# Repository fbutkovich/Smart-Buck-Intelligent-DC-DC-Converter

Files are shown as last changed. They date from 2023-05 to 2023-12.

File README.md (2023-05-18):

# Smart Buck Intelligent DC-DC Converter
Buck topology voltage converter with power monitoring functionality using the TI INA219 current sense IC.

The provided package includes the source code, necessary dependencies, PCB design, and 3D model files for a buck topology printed circuit board. This PCB is designed to efficiently power various devices, including a dedicated astronomy camera, using a higher voltage lithium-ion battery as the input source. A notable feature of this project design is the inclusion of power monitoring functionality through the utilization of the Texas Instruments INA219 Zero-Drift current/power monitor integrated circuit. The converter's output is a regulated 12 volts DC, capable of delivering up to 3 amperes of current, achieved by employing the Texas Instruments LM2596 SIMPLE SWITCHER 3A Step-Down Voltage Regulator. This configuration proves particularly beneficial when powering a dedicated astrophotography camera with active CMOS sensor cooling. The ability to monitor the camera's power consumption in relation to the fixed temperature setpoint and the surrounding environmental temperature adds significant value to this setup.

The barrel jack style connectors used for the voltage input and output are standard 5.5x2.1mm size, which is very common amongst astronomy equipment and many other consumer electronics.

The embedded firmware for the converter runs on the Microchip SAMD21E17A ARM Cortex M0 microcontroller, and can relay power monitoring statistics to a connected computer over a serial communications port.

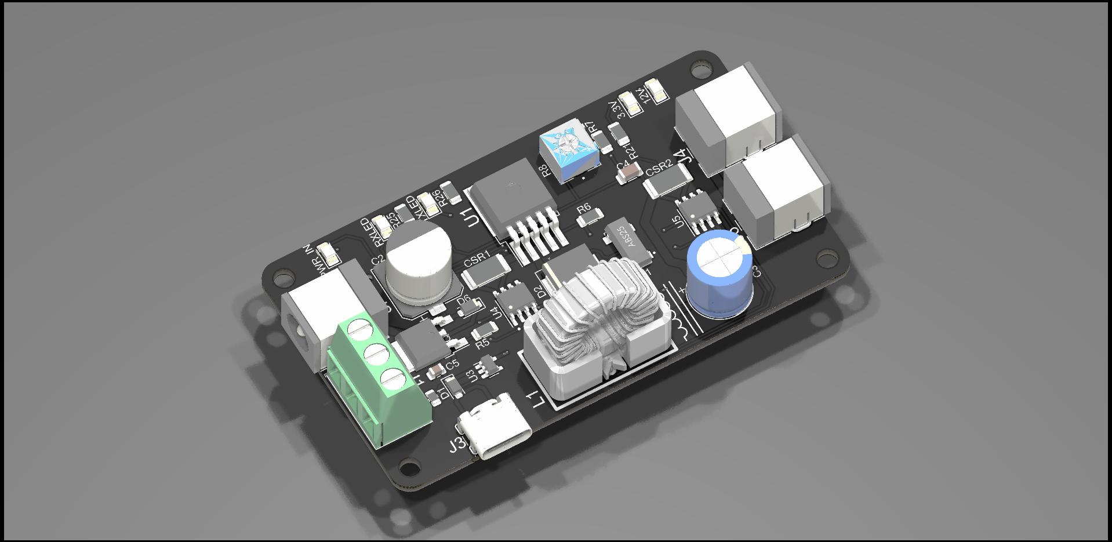
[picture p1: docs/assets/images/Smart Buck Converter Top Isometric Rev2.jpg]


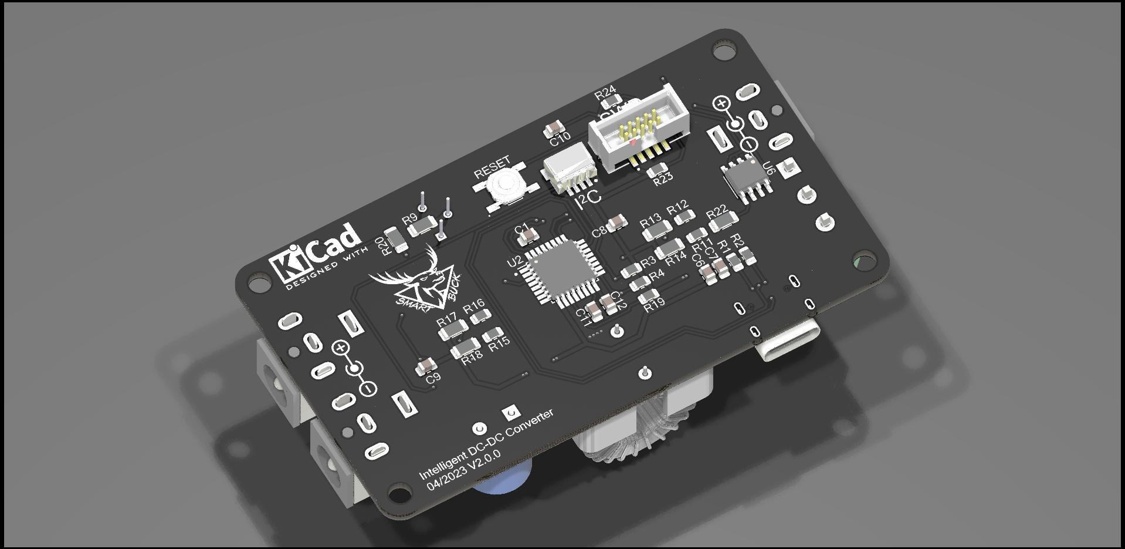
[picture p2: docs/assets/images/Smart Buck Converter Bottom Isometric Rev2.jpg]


The input screw terminal block is intended to be connected to a power tool battery using an “power wheels adapter”, which is fundamentally a flying lead breakout for the voltage of common power tool battery packs (Dewalt, Milwaukee, Makita etc.) that allows replacement of the standard lead-acid battery that comes in most childrens motorized cars.

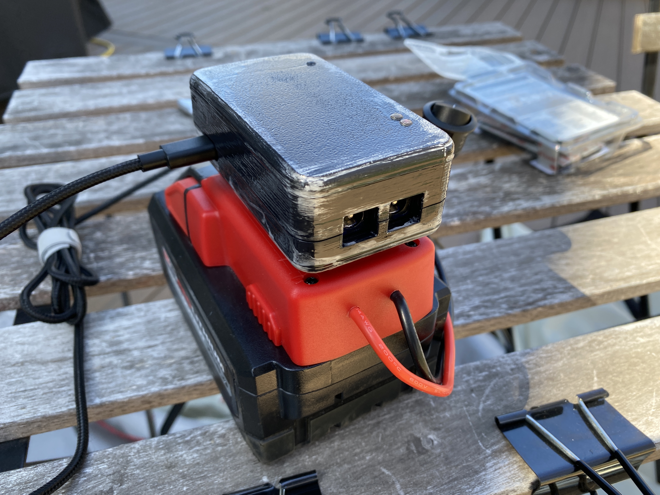
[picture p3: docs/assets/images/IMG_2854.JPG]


After the order and assembly of the first revision, as to be expected with any new electronic design there were several mistakes I ended up throubleshooting, thus leading to a few cuts and jumpers on the PCB itself. All of the corrections to the initial design were translated to the current revision of the schematic and layout and include:

* Ground plane disconnected from GND pins of U2, causing numerous headaches when attempting to flash bootloader onto IC and debug.
* Wrong pinout on U6, causing GND to be disconnected and frying IC upon first powerup. STCS05DR symbol and footprint were downloaded directly  from SnapEDA, however it was later discovered they were incorrect for KiCad.
* SWCLK signal needed 1kOhm pullup resistor for the SWD interface to work properly.
* Pinout of reset button was incorrect, again this components (TL3342F160QG) symbol and footprint for KiCad were sourced from SnapEDA, however the symbol led to the ground being connected to pushbutton in the normally     closed position, causing the microcontroller to be in a constant state of reset.
* Footprint size and capacity of feed-forward capacitor required for the LM2596 adjustable buck regulator were incorrect.

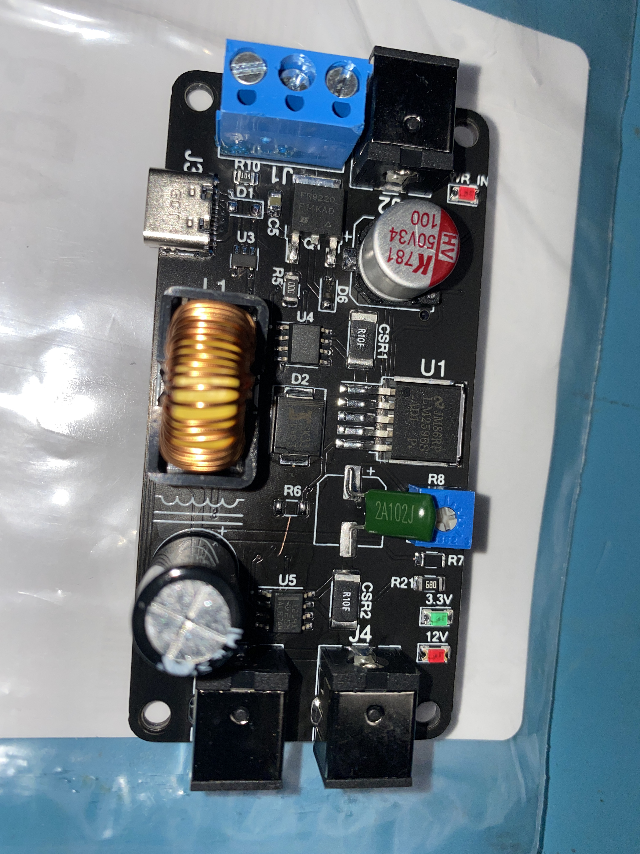
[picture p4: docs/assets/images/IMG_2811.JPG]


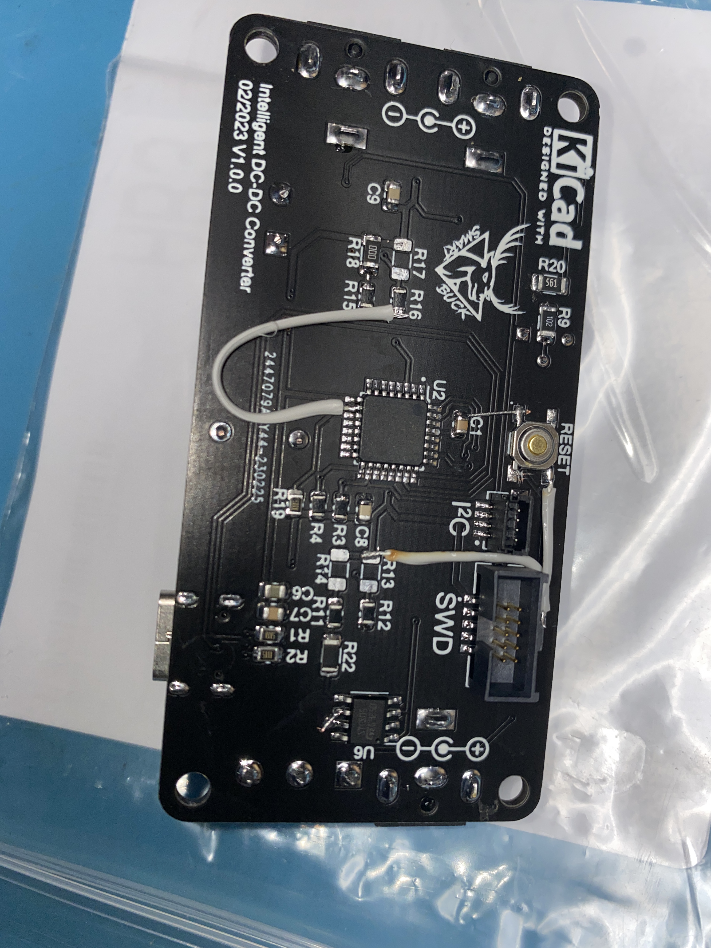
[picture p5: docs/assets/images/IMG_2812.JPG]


# Known Issues
* The onboard 3.3V regulator can be fed from dual voltage supplies, either the USB input, or the 18V battery input. Diodes D1 and D6 (PMEG3015EH) are placed on each voltage rail before tying together at the regulator VIN. After a few uses of the design, it was discovered that D1 had burnt up as the onboard microcontroller would no longer show up in windows as a COM port, and the 3.3V indicator LED would not light up, if an 18V battery was not also connected. The only reason I could think of on why D1 would malfunction would be a higher than rated reverse current due to such a high reverse voltage from the battery input (typically 16-22V) being imposed on the diode, the datasheet specs the reverse current anywhere between 400-1000uA when VR=30V, which is not being exceeded in this use case, however, this also strongly depends on the ambient temperature. I know for a fact that the inside of the enclosure the smart buck PCB is housed in gets considerablly warm when there is a large amount of power draw, which could be what is shortening the lifespan of the diodes. I haven't had time yet to find a suitible replacement diode that will be more robust.

# Project Goal
The primary objective of this project is to develop a compact and high-performance portable power bank that caters specifically to applications requiring 12VDC. The aim is to match the capabilities of commercially available alternatives like the Jackery power station, Celestron PowerTank, and Apertura Portable Telescope Power Supply. Not only does this design excel in size reduction, but it also offers superior performance monitoring and control. By accommodating a variable input DC voltage, which can be sourced from a wide range of commonly available power tool batteries from various manufacturers, the versatility of this power bank is limitless.

I believe the thorough documentation of this electronics project has instilled in me enough confidence to share it with the community as an open-source endeavor. I enthusiastically welcome further contributions to enhance both the hardware design and software implementation. Moreover, I'm open to ideas for additional features and improved functionality, as collaboration and innovation are key factors in driving this project forward.

# License
MIT license

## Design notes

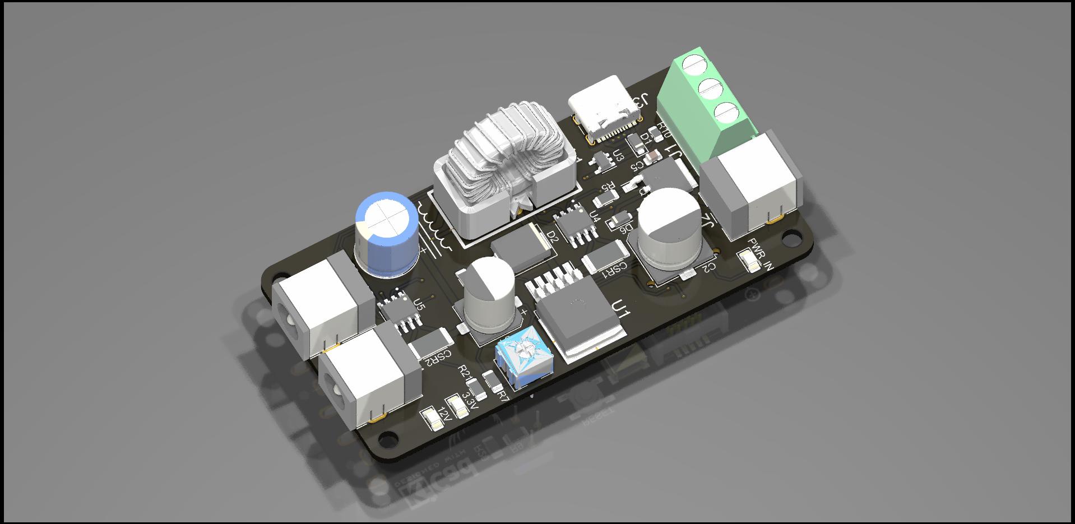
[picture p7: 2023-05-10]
docs/assets/images/Smart Buck Converter Top Isometric.jpg

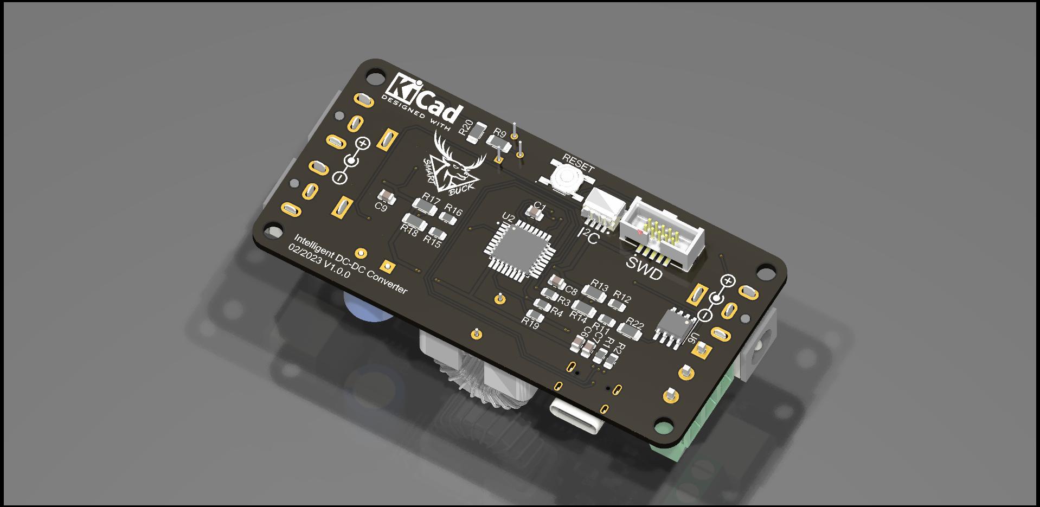
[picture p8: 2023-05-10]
docs/assets/images/Smart Buck Converter Bottom Isometric.jpg

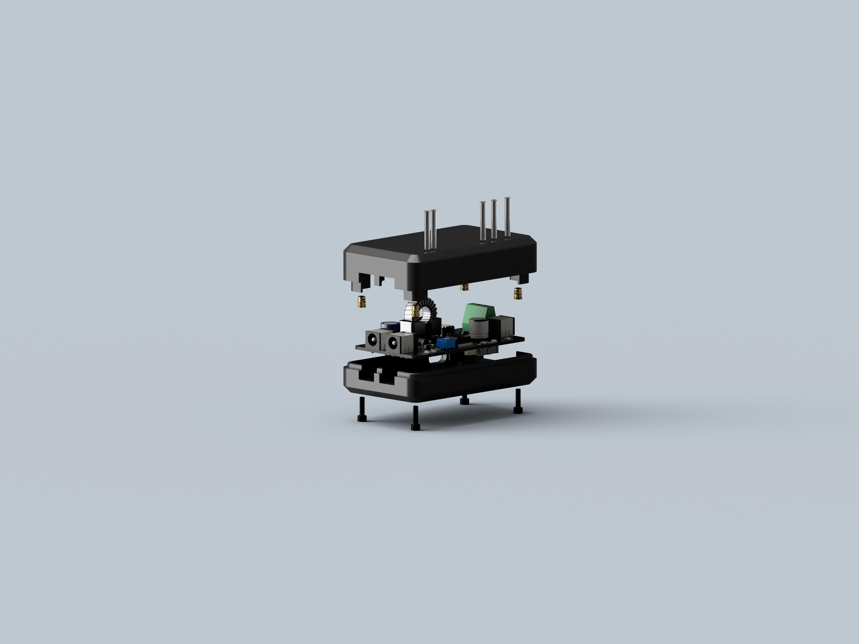
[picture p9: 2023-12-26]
Smart Buck Converter/Render.jpg

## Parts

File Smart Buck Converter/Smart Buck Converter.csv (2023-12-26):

REF | QTY | PN | Footprint | DESC | DNP?
C1, C7 | 2 | 1uF | Capacitor_SMD:C_0805_2012Metric | Unpolarized capacitor, small symbol
C2 | 1 | 100uF | Capacitor_SMD:CP_Elec_10x10.5 | Polarized capacitor
C3 | 1 | 1000uF | Capacitor_THT:CP_Radial_D10.0mm_P5.00mm | Polarized capacitor
C4 | 1 | 1nF | Capacitor_SMD:C_1206_3216Metric | Unpolarized capacitor
C5, C6 | 2 | 10uF | Capacitor_SMD:C_0805_2012Metric | Unpolarized capacitor, small symbol
C8, C9, C10 | 3 | 0.1uF | Capacitor_SMD:C_0805_2012Metric | Unpolarized capacitor, small symbol
C11, C12 | 2 | 22pF | Capacitor_SMD:C_0805_2012Metric | Unpolarized capacitor, small symbol
CSR1, CSR2 | 2 | 0.1 | Resistor_SMD:R_2512_6332Metric | Resistor
D1, D6 | 2 | CDBMHT340-HF | Diode_SMD:D_SOD-123F | 30V, 1.5A ultra low Vf MEGA Schottky barrier rectifier, SOD-123F
D2 | 1 | SK33 | Diode_SMD:D_SMC
D3, D5 | 2 | CMD15-21VRD/TR8 | LED_SMD:LED_1206_3216Metric | Light emitting diode
D4 | 1 | CMD15-21VGD/TR8 | LED_SMD:LED_1206_3216Metric | Light emitting diode
J1 | 1 | 6.91102E+11 | TerminalBlock_Phoenix:TerminalBlock_Phoenix_MKDS-1,5-3_1x03_P5.00mm_Horizontal | Generic connector, single row, 01x03, script generated (kicad-library-utils/schlib/autogen/connector/)
J2, J4, J6 | 3 | PJ-063AH | Connector_BarrelJack:BarrelJack_CUI_PJ-063AH_Horizontal | DC Barrel Jack with an internal switch
J3 | 1 | USB4105-GF-A | Connector_USB:USB_C_Receptacle_GCT_USB4105-xx-A_16P_TopMnt_Horizontal | USB 2.0-only Type-C Receptacle connector
J5 | 1 | SHF-105-01-L-D-SM | User Components:SAMTEC_SHF-105-01-L-D-SM | Cortex Debug Connector, standard ARM Cortex-M SWD and JTAG interface
J7 | 1 | BM04B-SRSS-TBT(LF)(SN) | User Components:CONN_BM04B-SRSS-TBT(LF)(SN)
L1 | 1 | PE-54039NL | User Components:PE-54039NL | Power Inductors - Leaded 53uH 3A
Q1 | 1 | IRFR9220TRPBF-BE3 | Package_TO_SOT_SMD:TO-252-2 | MOSFET P-CH, 200V, 3.6A
R1, R2, R19 | 3 | 5.1k | Resistor_SMD:R_0805_2012Metric | Resistor
R3, R4, R11, R12, R15, R16 | 6 | 10.0k | Resistor_SMD:R_0805_2012Metric | Resistor
R5, R6, R13, R14, R17, R18 | 6 | 0 | Resistor_SMD:R_1206_3216Metric | Resistor
R7 | 1 | 8.2k | Resistor_SMD:R_1206_3216Metric | Resistor
R8 | 1 | 1.0k | User Components:TRIM_3362P-1-103 | Trim-potentiometer
R9 | 1 | 1.0k | Resistor_SMD:R_1206_3216Metric | Resistor
R10 | 1 | 100k | Resistor_SMD:R_0805_2012Metric | Resistor
R20 | 1 | 560 | Resistor_SMD:R_1206_3216Metric | Resistor
R21 | 1 | 68 | Resistor_SMD:R_1206_3216Metric | Resistor
R22 | 1 | 5 | Resistor_SMD:R_1206_3216Metric | Resistor
R23 | 1 | 1.0k | Resistor_SMD:R_0805_2012Metric | Resistor
R24 | 1 | 330 | Resistor_SMD:R_0805_2012Metric | Resistor
R25, R26 | 2 | 1k | Resistor_SMD:R_1206_3216Metric | Resistor
R27, R28 | 2 | 0 | Resistor_SMD:R_0805_2012Metric | Resistor
RXLED1 | 1 | CMD15-21VYC/TR8 | LED_SMD:LED_1206_3216Metric | Light emitting diode
SW1 | 1 | TL3342F160QG | User Components:SW_TL3342F160QG | Push button switch, generic, two pins
TXLED1 | 1 | CMD15-21VYC/TR8 | LED_SMD:LED_1206_3216Metric | Light emitting diode
U1 | 1 | LM2596S-ADJ | Package_TO_SOT_SMD:TO-263-5_TabPin3 | Adjustable 3A Step-Down Voltage Regulator, TO-263
U2 | 1 | ATSAMD21E18A-A | Package_QFP:TQFP-32_7x7mm_P0.8mm | SAM D21 Microchip SMART ARM-based Flash MCU, 48Mhz, 256K Flash, 32K SRAM, TQFP-32
U3 | 1 | AP2204K-3.3 | Package_TO_SOT_SMD:SOT-23-5 | 150mA low dropout linear regulator, wide input voltage range, 3.3V fixed positive output, SOT-23-5
U4, U5 | 2 | INA219AxD | Package_SO:SOIC-8_3.9x4.9mm_P1.27mm | Zero-Drift, Bidirectional Current/Power Monitor (0-26V) With I2C Interface, SOIC-8
U6 | 1 | STCS05DR | Package_SO:SOIC-8_3.9x4.9mm_P1.27mm | LED Driver 0.5A max, 40V Max Input, 8-SOIC Package
X1 | 1 | 830003000 | User Components:XTAL_ABS25-32.768KHZ-6-1-T | Two pin crystal

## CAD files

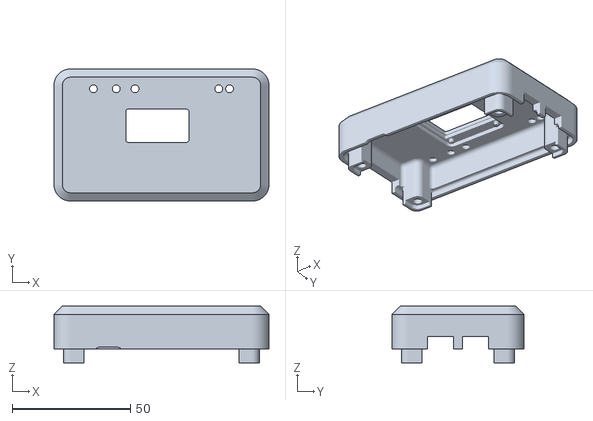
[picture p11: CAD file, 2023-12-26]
Smart Buck Converter/Enclosure_TOP.stl
90.8 x 55.8 x 24.0

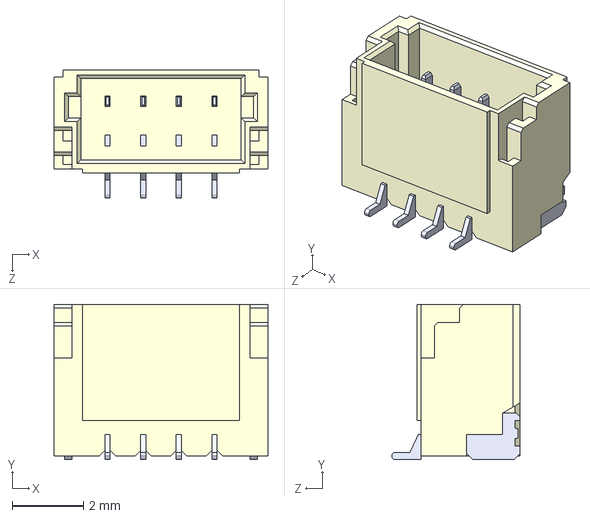
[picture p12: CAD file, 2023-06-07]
Smart Buck Converter/KiCad Library/3dmodels/BM04B-SRSS-TBT_LF__SN_.step
6.00 x 4.35 x 3.60 mm

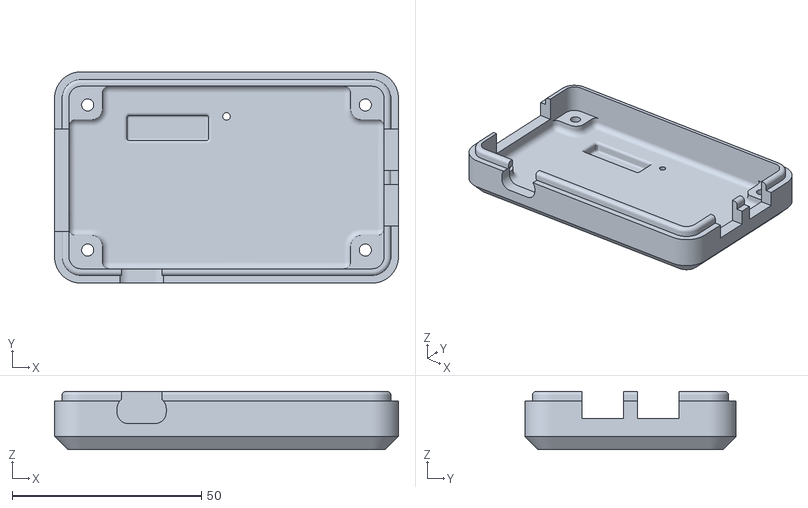
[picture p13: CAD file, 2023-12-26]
Smart Buck Converter/Enclosure_BOTTOM.stl
90.8 x 55.8 x 15.3

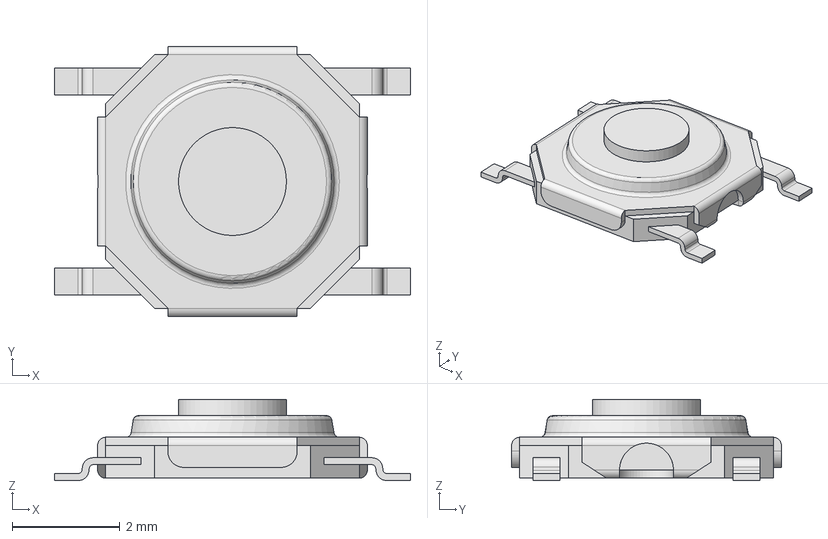
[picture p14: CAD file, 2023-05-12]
Smart Buck Converter/KiCad Library/3dmodels/TL3342F160QG.step
6.60 x 5.00 x 1.50 mm

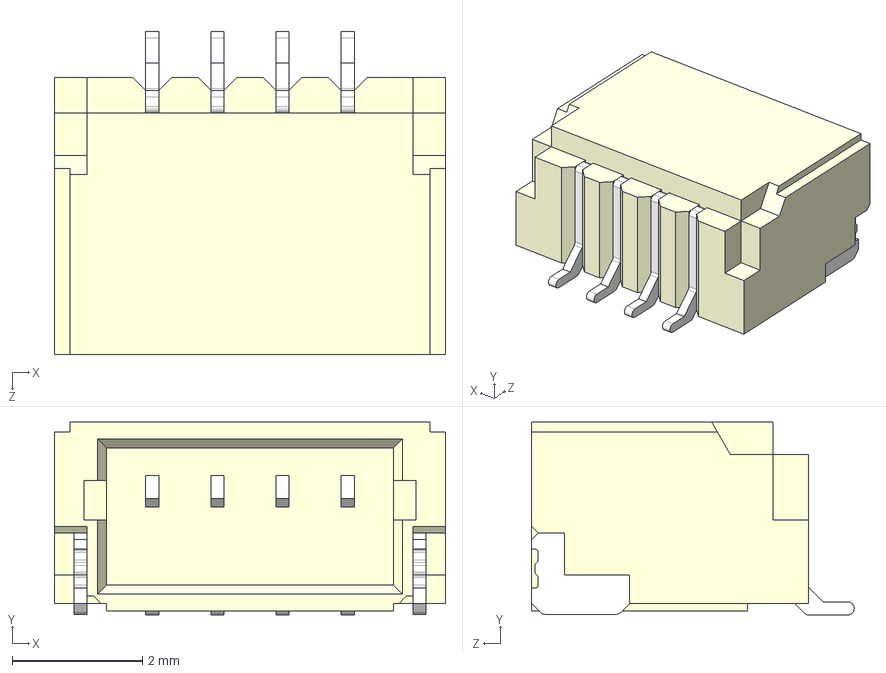
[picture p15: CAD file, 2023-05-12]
Smart Buck Converter/KiCad Library/3dmodels/SM04B-SRSS-TB_LF__SN_.step
6.00 x 2.96 x 4.95 mm

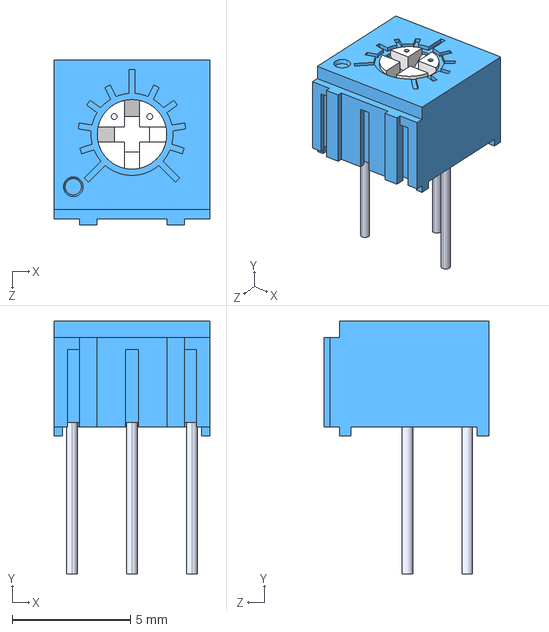
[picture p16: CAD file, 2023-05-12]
Smart Buck Converter/KiCad Library/3dmodels/3362P-1-103.step
6.60 x 10.7 x 6.99 mm

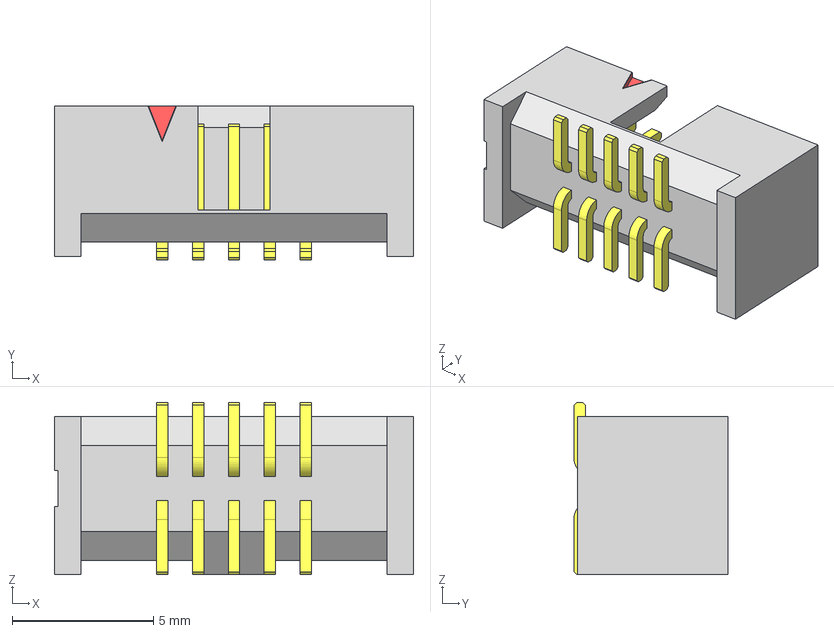
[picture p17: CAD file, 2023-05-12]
Smart Buck Converter/KiCad Library/3dmodels/SHF-105-01-L-D-SM.step
12.7 x 5.46 x 6.10 mm
T-1S71-02-05-D-SM
SHF-First_Position_Indicator
SHF-105-01-D_header

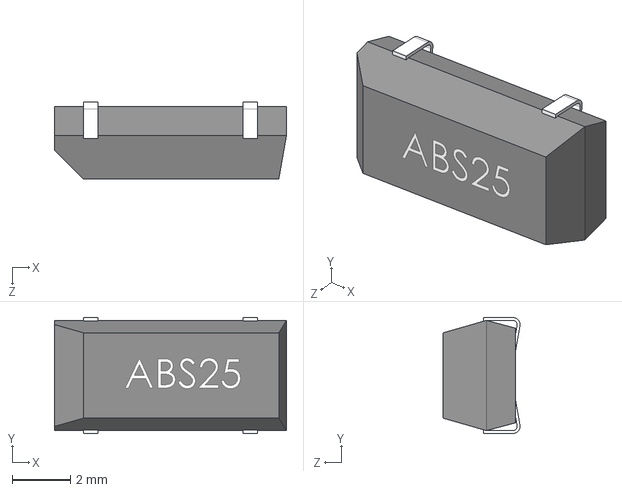
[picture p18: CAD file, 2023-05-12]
Smart Buck Converter/KiCad Library/3dmodels/ABS25-32.768KHZ-T.step
8.00 x 4.00 x 2.66 mm

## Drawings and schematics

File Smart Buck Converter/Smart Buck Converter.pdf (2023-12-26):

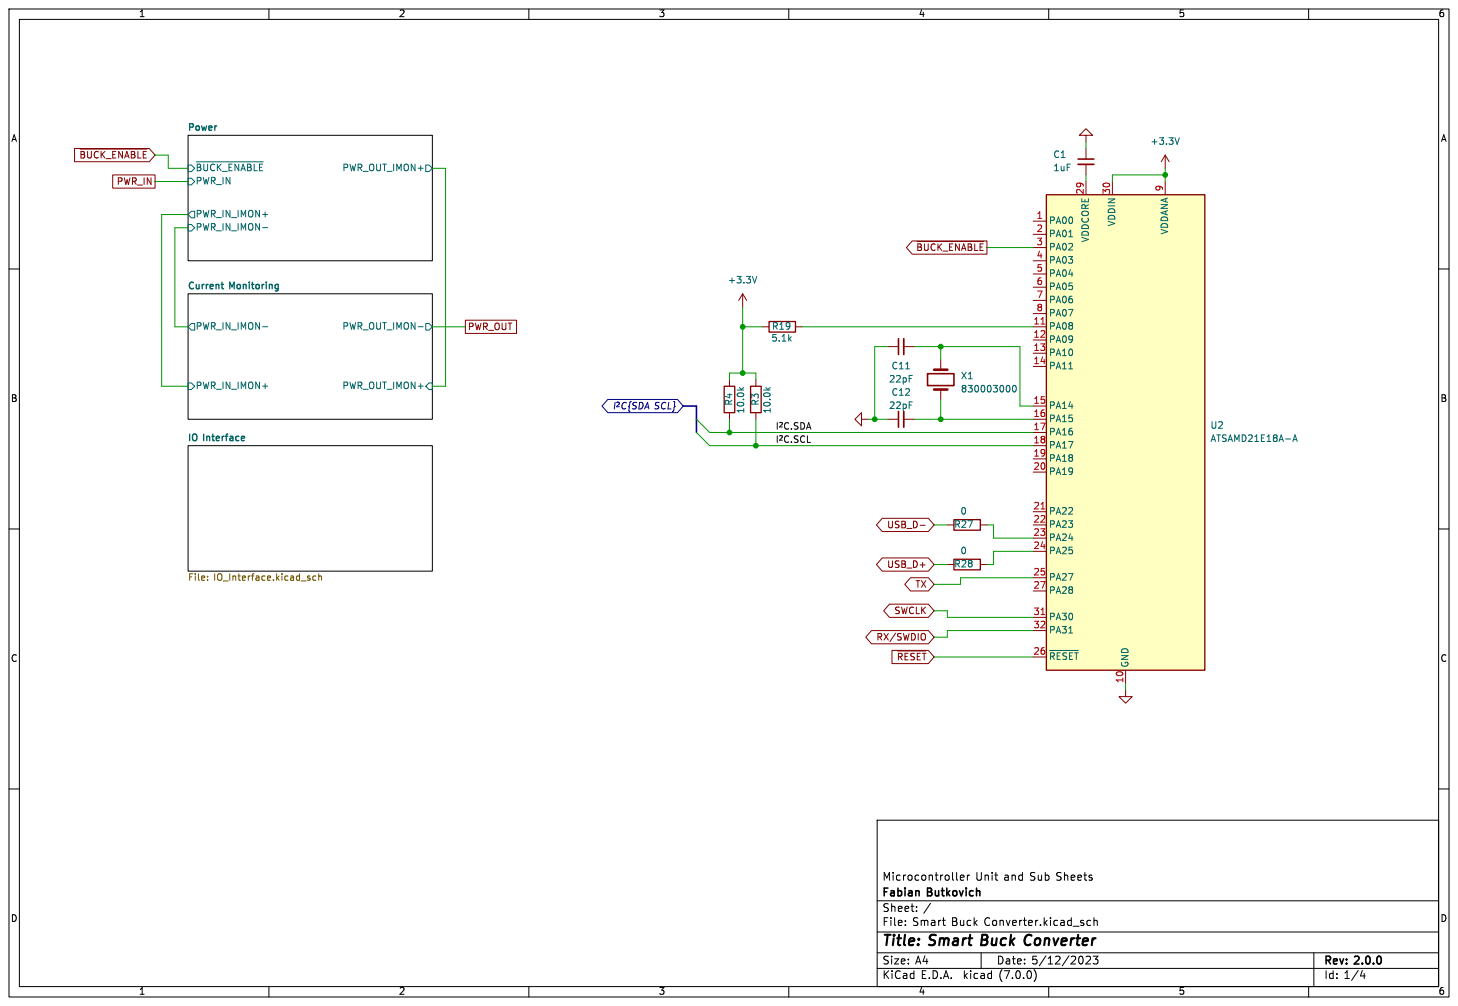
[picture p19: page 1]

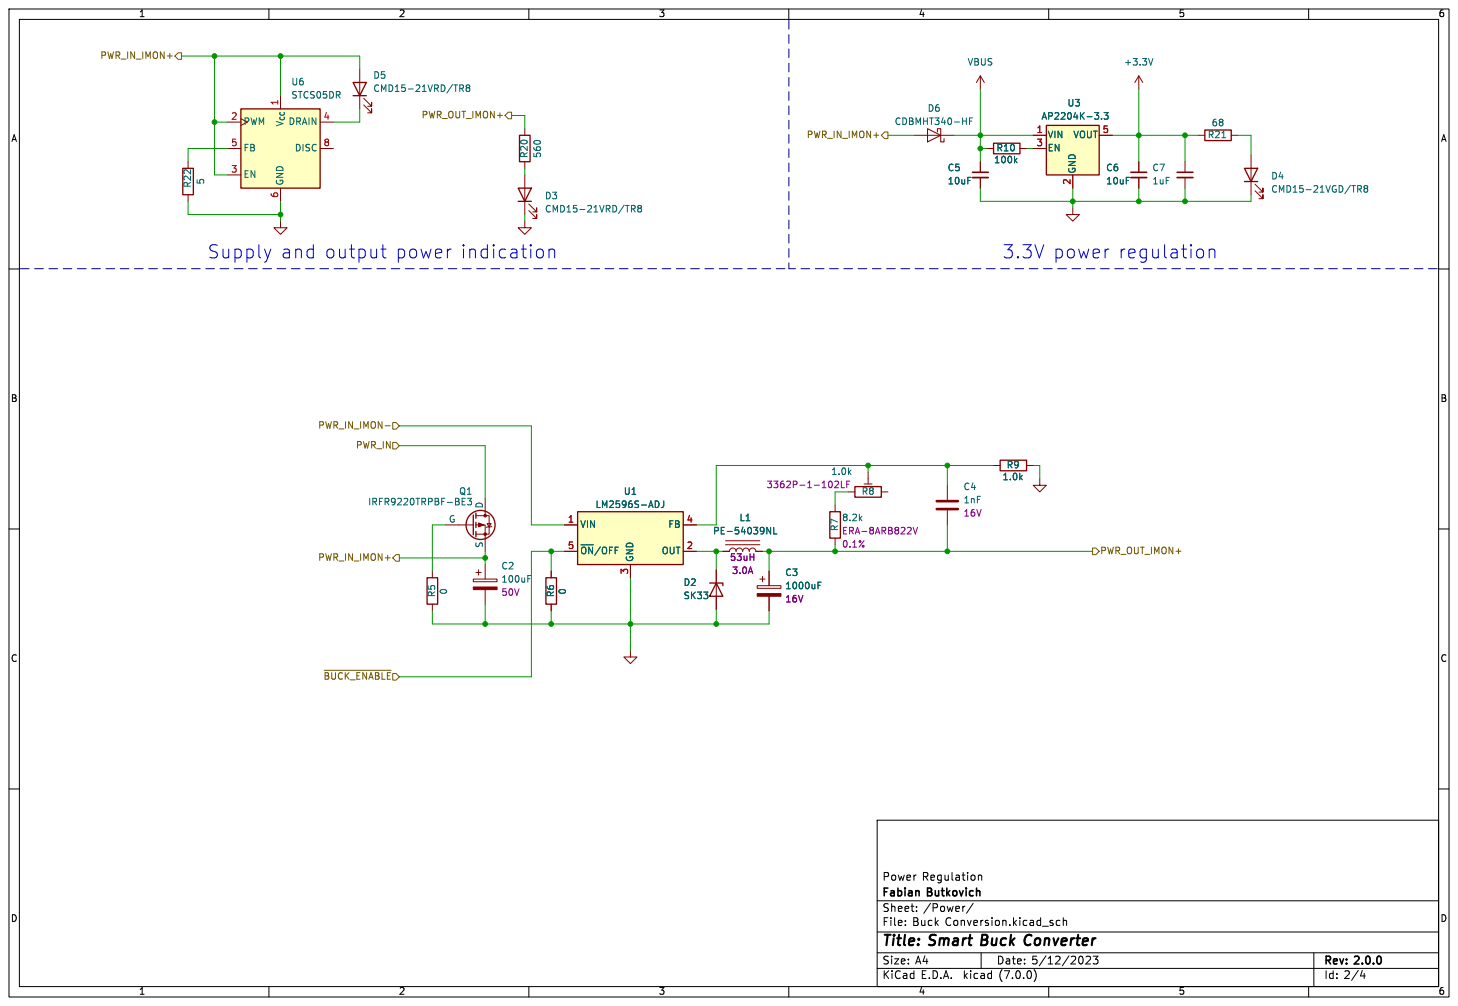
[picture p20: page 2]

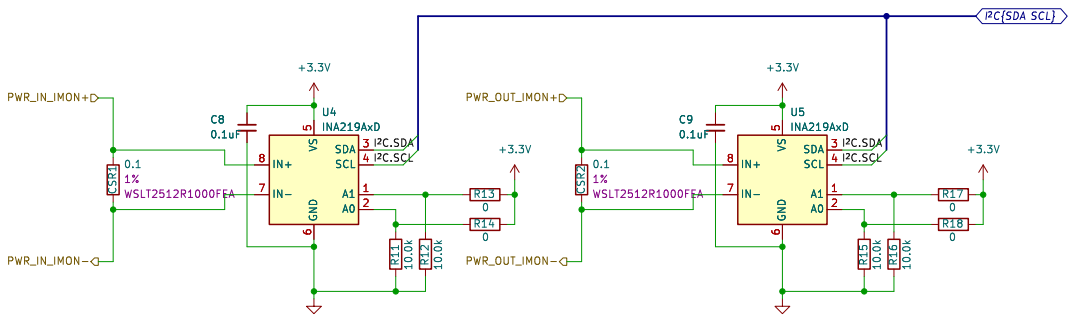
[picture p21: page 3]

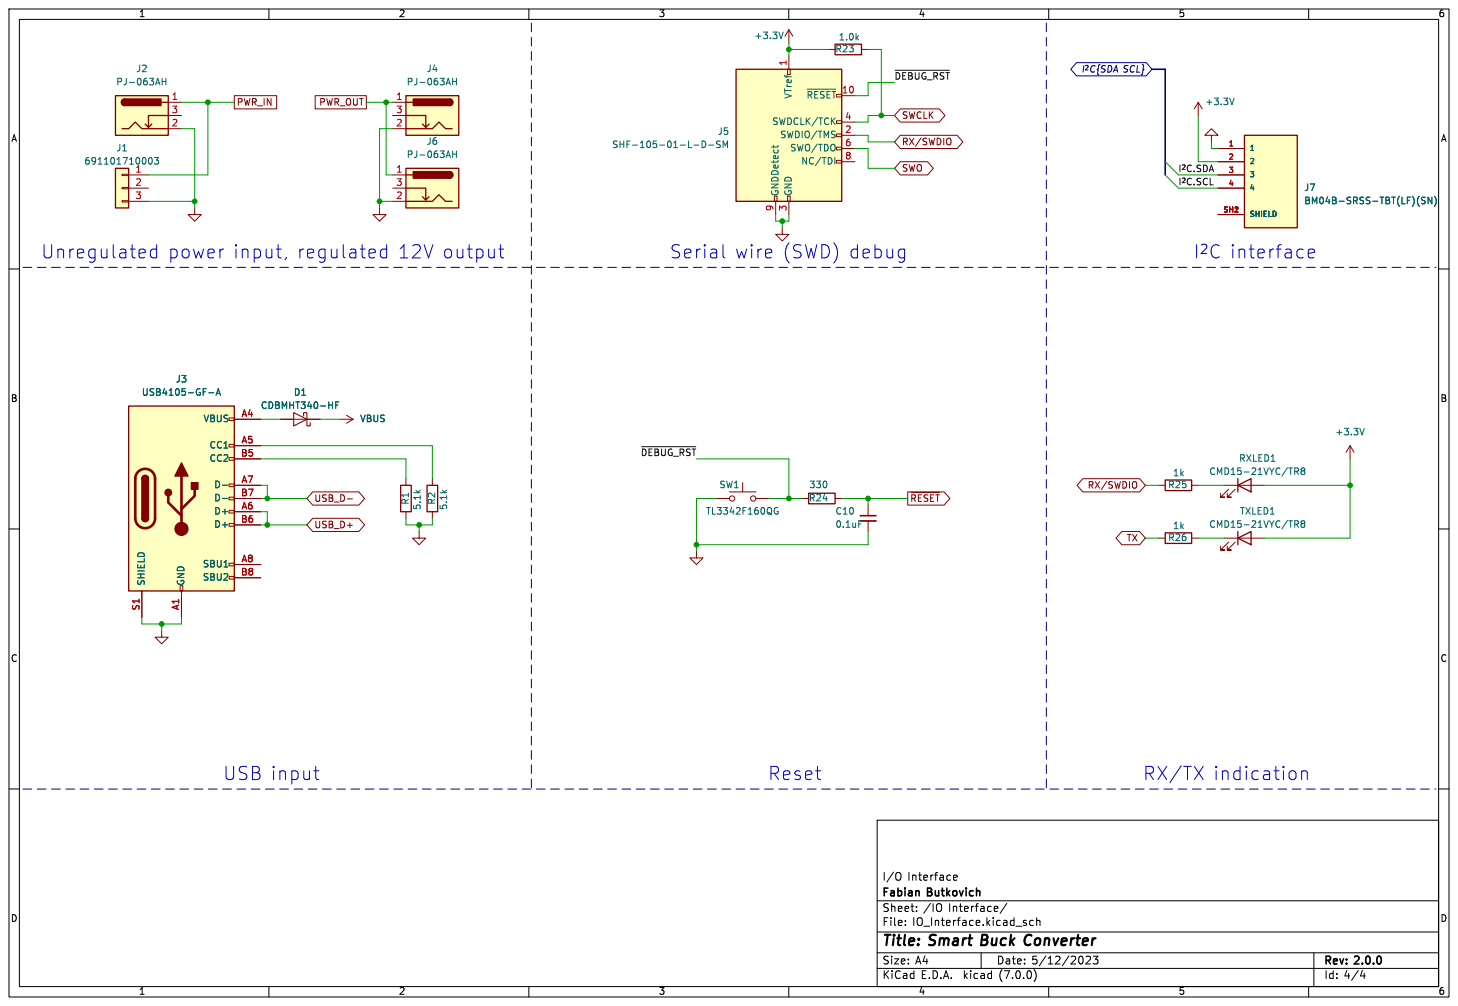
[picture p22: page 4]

~{RESET} SWCLK RX/SWDIO

3 SWDCLK/TCK 4 SWO/TDO 6 NC/TDI 8 GNDDetect 9

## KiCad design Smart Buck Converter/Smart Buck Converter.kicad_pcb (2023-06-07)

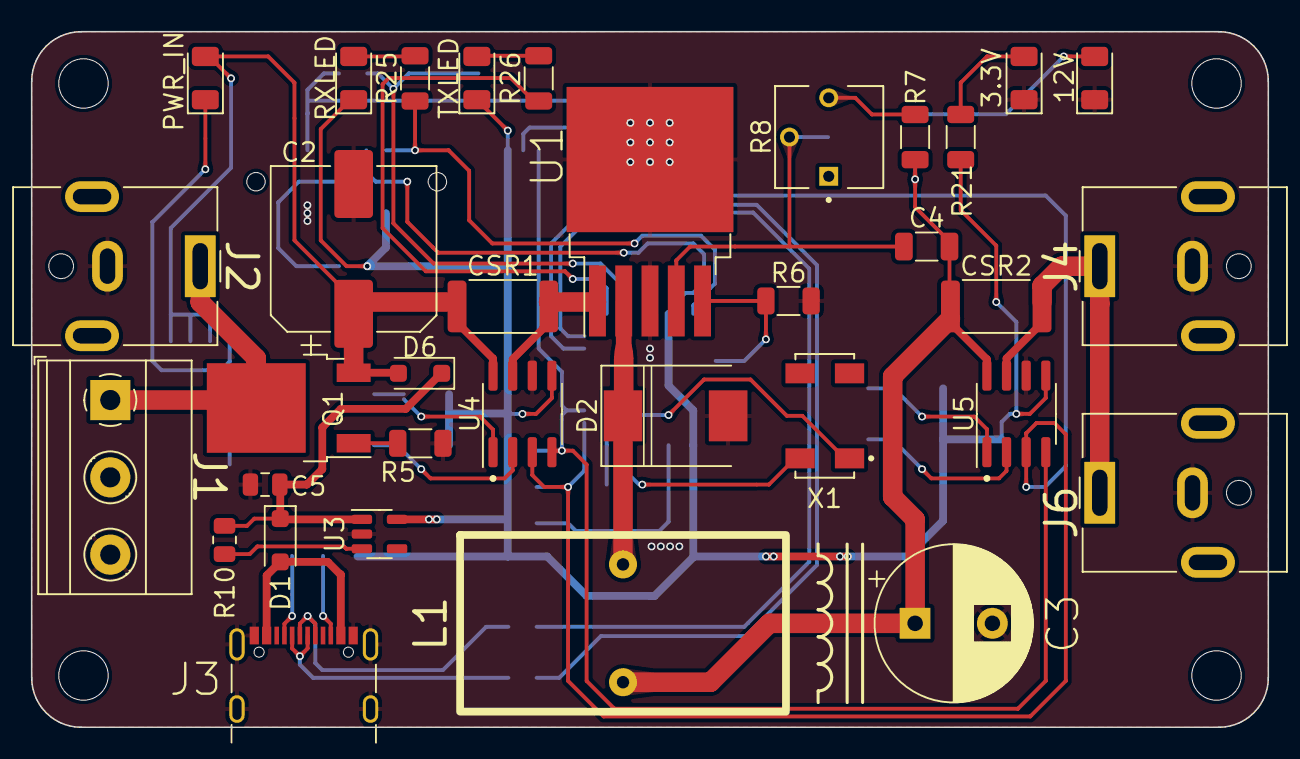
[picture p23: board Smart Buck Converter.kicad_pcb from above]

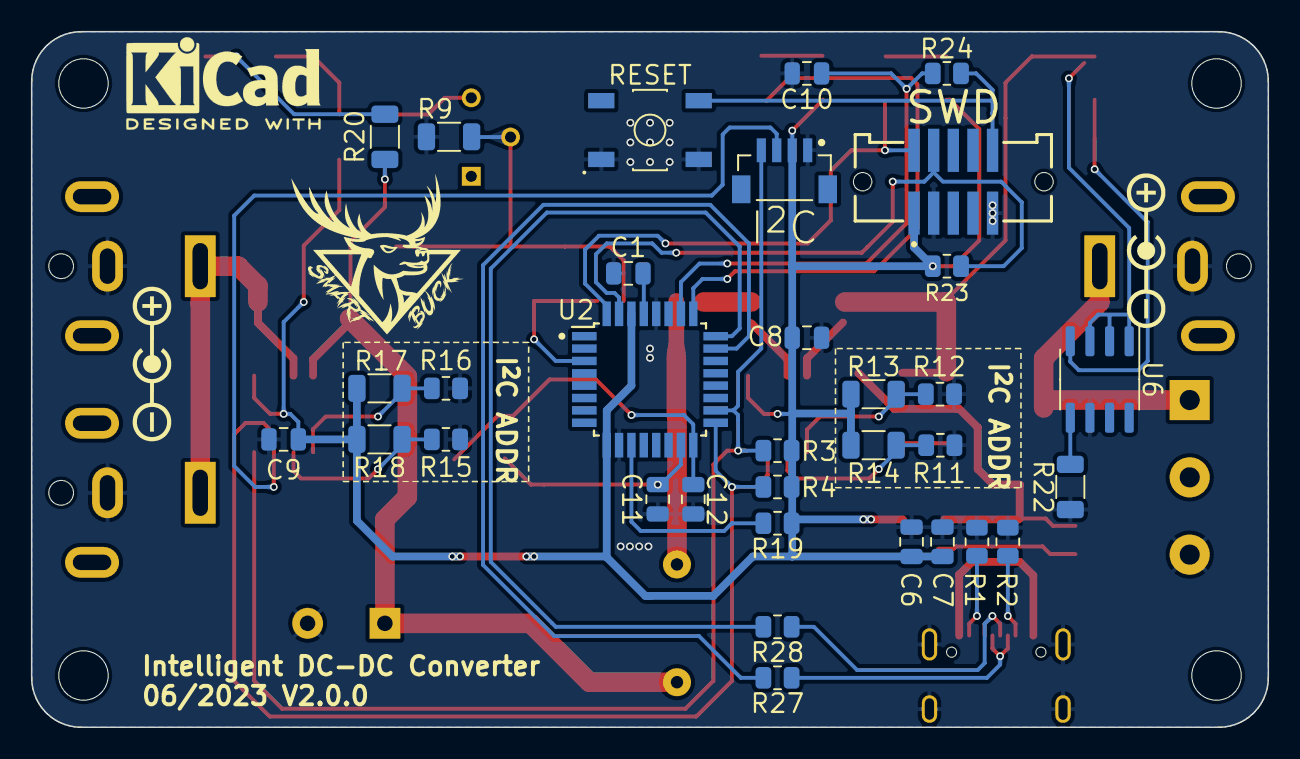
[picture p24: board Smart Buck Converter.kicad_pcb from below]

Board: 2 copper layers, 80.0 x 45.0 mm, 67 parts (33 on the bottom side), 40 nets.

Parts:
3.3V: CMD15-21VGD/TR8; LED_1206_3216Metric
12V: CMD15-21VRD/TR8; LED_1206_3216Metric
C1, C7: 1uF; C_0805_2012Metric
C2: 100uF; CP_Elec_10x10.5
C3: 1000uF; CP_Radial_D10.0mm_P5.00mm
C4: 1nF; C_1206_3216Metric
C5, C6: 10uF; C_0805_2012Metric
C8, C9, C10: 0.1uF; C_0805_2012Metric
C11, C12: 22pF; C_0805_2012Metric
CSR1, CSR2: 0.1; R_2512_6332Metric
D1, D6: CDBMHT340-HF; D_SOD-123F
D2: SK33; D_SMC
I^{2}C: SM04B-SRSS-TB(LF)(SN); CONN_BM04B-SRSS-TBT(LF)(SN)
J1: 691101710003; TerminalBlock_Phoenix_MKDS-1,5-3_1x03_P5.00mm_Horizontal
J2, J4, J6: PJ-063AH; BarrelJack_CUI_PJ-063AH_Horizontal
J3: USB4105-GF-A; USB_C_Receptacle_GCT_USB4105-xx-A_16P_TopMnt_Horizontal
L1: PE-54039NL
PWR_IN: CMD15-21VRD/TR8; LED_1206_3216Metric
Q1: IRFR9220TRPBF-BE3; TO-252-2
R1, R2, R19: 5.1k; R_0805_2012Metric
R3, R4, R11, R12, R15, R16: 10.0k; R_0805_2012Metric
R5, R6, R13, R14, R17, R18: 0; R_1206_3216Metric
R7: 8.2k; R_1206_3216Metric
R8: 1.0k; TRIM_3362P-1-103
R9: 1.0k; R_1206_3216Metric
R10: 100k; R_0805_2012Metric
R20: 560; R_1206_3216Metric
R21: 68; R_1206_3216Metric
R22: 5; R_1206_3216Metric
R23: 1.0k; R_0805_2012Metric
R24: 330; R_0805_2012Metric
R25, R26: 1k; R_1206_3216Metric
R27, R28: 0; R_0805_2012Metric
RESET: TL3342F160QG; SW_TL3342F160QG
RXLED: CMD15-21VYC/TR8; LED_1206_3216Metric
SWD: SHF-105-01-L-D-SM; SAMTEC_SHF-105-01-L-D-SM
TXLED: CMD15-21VYC/TR8; LED_1206_3216Metric
U1: LM2596S-ADJ; TO-263-5_TabPin3
U2: ATSAMD21E18A-A; TQFP-32_7x7mm_P0.8mm
U3: AP2204K-3.3; SOT-23-5
U4, U5: INA219AxD; SOIC-8_3.9x4.9mm_P1.27mm
U6: STCS05DR; SOIC-8_3.9x4.9mm_P1.27mm
X1: 830003000; XTAL_ABS25-32.768KHZ-6-1-T

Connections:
+3V3: C6.1, C7.1, C8.1, C9.1, I^{2}C.2, R3.1, R4.1, R13.2, R14.2, R17.2, R18.2, R19.1, R21.1, R23.1, RXLED.1 (K), SWD.01, TXLED.1 (K), U2.9 (VDDANA), U2.30 (VDDIN), U3.5 (VOUT), U4.5 (VS), U5.5 (VS)
/Current Monitoring/PWR_IN_IMON+: C2.1, CSR1.1, D6.2 (A), PWR_IN.2 (A), Q1.3 (S), U4.8 (IN+), U6.1 (V_{CC}), U6.2 (PWM), U6.3 (EN)
/Current Monitoring/PWR_IN_IMON-: CSR1.2, U1.1 (VIN), U4.7 (IN-)
/Current Monitoring/PWR_OUT_IMON+: C3.1, C4.2, CSR2.1, L1.2, R7.2, R20.1, U5.8 (IN+)
/IO Interface/~DEBUG_RST: R24.1, RESET.4, SWD.10
GND: 3.3V.1 (K), 12V.1 (K), C1.1, C2.2, C3.2, C5.2, C6.2, C7.2, C8.2, C9.2, C10.2, C11.1, C12.1, D2.2 (A), I^{2}C.1, J1.3, J2.2, J3.A1 (GND), J3.A12 (GND), J3.B1 (GND), J3.B12 (GND), J3.S1 (SHIELD), J4.2, J6.2, R1.2, R2.2, R5.2, R6.2, R9.2, R11.2, R12.2, R15.2, R16.2, R22.2, RESET.1, RESET.2, SWD.03, SWD.09, U1.3 (GND), U2.10 (GND), U2.28 (GND), U3.2 (GND), U4.6 (GND), U5.6 (GND), U6.6 (GND)
I^{2}C.SCL: I^{2}C.4, R3.2, U2.18 (PA17), U4.4 (SCL), U5.4 (SCL)
I^{2}C.SDA: I^{2}C.3, R4.2, U2.17 (PA16), U4.3 (SDA), U5.3 (SDA)
unnamed: D1.2 (A), J3.A4 (VBUS), J3.A9 (VBUS), J3.B4 (VBUS), J3.B9 (VBUS)
unnamed: D2.1 (K), L1.1, U1.2 (OUT)
unnamed: 12V.2 (A), R20.2
unnamed: 3.3V.2 (A), R21.2
unnamed: PWR_IN.1 (K), U6.4 (DRAIN)
unnamed: J3.A5 (CC1), R2.1
unnamed: J3.B5 (CC2), R1.1
unnamed: Q1.1 (G), R5.1
unnamed: R7.1, R8.3
unnamed: R25.2, RXLED.2 (A)
unnamed: R26.2, TXLED.2 (A)
unnamed: C4.1, R8.2, R9.1, U1.4 (FB)
unnamed: R19.2, U2.11 (PA08)
unnamed: C11.2, U2.15 (PA14), X1.4
unnamed: C12.2, U2.16 (PA15), X1.1
unnamed: C1.2, U2.29 (VDDCORE)
unnamed: R10.2, U3.3 (EN)
unnamed: R11.1, R14.1, U4.2 (A0)
unnamed: R12.1, R13.1, U4.1 (A1)
unnamed: R15.1, R18.1, U5.2 (A0)
unnamed: R16.1, R17.1, U5.1 (A1)
unnamed: R22.1, U6.5 (FB)
PWR_IN: J1.1, J2.1, Q1.2 (D)
PWR_OUT: CSR2.2, J4.1, J6.1, U5.7 (IN-)
RX/SWDIO: R25.1, SWD.02, U2.32 (PA31)
SWCLK: R23.2, SWD.04, U2.31 (PA30)
TX: R26.1, U2.25 (PA27)
USB_D+: J3.A6 (D+), J3.B6 (D+), R28.1
USB_D-: J3.A7 (D-), J3.B7 (D-), R27.1
VBUS: C5.1, D1.1 (K), D6.1 (K), R10.1, U3.1 (VIN)
~BUCK_ENABLE: R6.1, U1.5 (~ON/OFF), U2.3 (PA02)
~RESET: C10.1, R24.2, U2.26 (~RESET)

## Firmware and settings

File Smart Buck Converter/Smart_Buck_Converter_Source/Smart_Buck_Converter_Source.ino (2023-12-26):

/*
  Source code for Smart Buck step-down voltage converter with power monitoring functionality using the Texas Instruments INA219 Zero-Drift current/power monitor.
  Input power to the physical circuit is intended to be an 18-22VDC lithium-ion battery source, while the output is 12VDC regulated up to 3A of current achieved by
  utilizing the Texas Instruments LM2596 SIMPLE SWITCHER 3A Step-Down Voltage Regulator.

  https://www.ti.com/lit/ds/symlink/ina219.pdf
  https://www.ti.com/lit/ds/symlink/lm2596.pdf

  Dependencies:
*   * Arduino Wire library
*   * INA219 library by DeCristofaro John, Jukka-Pekka Sarjanen, gandy92, Flavius Bindea, Robert Wolff

  This code was developed and tested to run on the Microchip SAMD21E17A ARM Cortex M0 microcontroller.

  March 2023 by Fabian Butkovich
*/

#include <Wire.h>
#include <INA219.h>
#include <Adafruit_GFX.h>
#include <Adafruit_SSD1306.h>

// Create instance for INA219 library class
INA219 PWR_IN_IMON;
// INA219 sensor for power output has different I2C address
INA219 PWR_OUT_IMON(INA219::I2C_ADDR_41);

// OLED display width, in pixels
#define SCREEN_WIDTH 128  
// OLED display height, in pixels
#define SCREEN_HEIGHT 64  

// OLED display reset pin # (or -1 if sharing Arduino reset pin)
#define OLED_RESET -1        
// See datasheet for Address; 0x3D for 128x64, 0x3C for 128x32
#define SCREEN_ADDRESS 0x3D  
Adafruit_SSD1306 display(SCREEN_WIDTH, SCREEN_HEIGHT, &Wire, OLED_RESET);

#define R_SHUNT 0.1
#define V_SHUNT_MAX 0.3
#define V_BUS_IN_MAX 32
#define V_BUS_OUT_MAX 16
#define I_MAX_EXPECTED 3
// How many samples to take and average for current measurments, different types of loads (resistive, capacitive etc.) on
// the regulated output can cause the over-current function to false trigger if for example there is a high startup current but then the
// value settles after a short period of time. Averaging N shunt current readings over a period of time can prevent this.
#define NUMSAMPLES 12
// SAMD21E17A PA02
#define BUCK_ENABLE 2

// Long positive integer for storing interval to wait before reading sensors, units are in milliseconds
unsigned long readinterval = 100;
unsigned long printinterval = 10000;
unsigned long previousMillis = 0;
unsigned long previousMillis2 = 0;

float I_IN_AVERAGE_PREVIOUS;
float I_IN_AVERAGE;
float I_OUT_AVERAGE_PREVIOUS;
float I_OUT_AVERAGE;

enum unit_type {
  voltage,
  current,
  power
};

void setup()
{
//  // Switch generic clock 0 (GCLK0) over to the 32.768kHz external crystal clock source
//  GCLK->GENCTRL.reg = //GCLK_GENCTRL_OE |            // Test: enable GCLK output (on a selected pin)
//    GCLK_GENCTRL_IDC |           // Set the duty cycle to 50/50 HIGH/LOW
//    GCLK_GENCTRL_GENEN |         // Enable GCLK0
//    GCLK_GENCTRL_SRC_XOSC32K |   // Set the external 32.768kHz clock source (XOSC32K)
//    GCLK_GENCTRL_ID(0);          // Select GCLK0
//  while (GCLK->STATUS.bit.SYNCBUSY);               // Wait for synchronization

  // Test: enable the GCLK0 output on D2 (PA14)
  PORT->Group[g_APinDescription[2].ulPort].PINCFG[g_APinDescription[2].ulPin].bit.PMUXEN = 1;
  PORT->Group[g_APinDescription[2].ulPort].PMUX[g_APinDescription[2].ulPin >> 1].reg |= PORT_PMUX_PMUXE_H;
  
  Serial.begin(115200);

  // Initially enable LM2596 simple switcher
  pinMode(BUCK_ENABLE, OUTPUT);
  digitalWrite(BUCK_ENABLE, LOW);

  // Begin I2C communication with and configure 1st INA219 used for input power source
  PWR_IN_IMON.begin();
  // Configure input for 26V max voltage and 3.2A max current @ 0.8mA resolution, averaging of 8 samples per sensor reading
  PWR_IN_IMON.configure(INA219::RANGE_32V, INA219::GAIN_8_320MV, INA219::ADC_8SAMP, INA219::ADC_8SAMP, INA219::CONT_SH_BUS);
  PWR_IN_IMON.calibrate(R_SHUNT, V_SHUNT_MAX, V_BUS_IN_MAX, I_MAX_EXPECTED);

  // Configure output for 16V max voltage and 3.2A max current @ 0.8mA resolution
  PWR_OUT_IMON.begin();
  PWR_OUT_IMON.configure(INA219::RANGE_16V, INA219::GAIN_8_320MV, INA219::ADC_8SAMP, INA219::ADC_8SAMP, INA219::CONT_SH_BUS);
  PWR_OUT_IMON.calibrate(R_SHUNT, V_SHUNT_MAX, V_BUS_OUT_MAX, I_MAX_EXPECTED);

  // SSD1306_SWITCHCAPVCC = generate display voltage from 3.3V internally
  if (!display.begin(SSD1306_SWITCHCAPVCC, SCREEN_ADDRESS)) 
  {
    Serial.println(F("SSD1306 allocation failed"));
    for (;;)
      ;  // Don't proceed, loop forever
  }
  // Clear the initial screen buffer
  display.clearDisplay();
  display.setTextWrap(false);
  display.setTextSize(1);
  display.setTextColor(SSD1306_WHITE);
}

void loop()
{
  // Use the millis() function which returns the number of milliseconds elapsed since the start of the code loop, this is used
  // to calculate how long to wait before polling the power monitoring sensors
  unsigned long currentMillis = millis();

  if (Serial.available() > 0)
  {
    // Read char array input from serial monitor and store it within a string datatype
    String input = Serial.readStringUntil('\n');
    if (input == "1")
    {
      digitalWrite(BUCK_ENABLE, LOW);
    }
    else if (input == "0")
    {
      digitalWrite(BUCK_ENABLE, HIGH);
    }
  }

  // Read and average current data at 10Hz (every 100ms)
  if (currentMillis - previousMillis >= readinterval)
  {
    // Restart the non-blocking millis() timer
    previousMillis = currentMillis;

    // Detect under-voltage and over-current events
    if (over_current_event() || under_voltage_event())
    {
      digitalWrite(BUCK_ENABLE, HIGH);
    }

    I_IN_AVERAGE_PREVIOUS = I_IN_AVERAGE;
    I_OUT_AVERAGE_PREVIOUS = I_OUT_AVERAGE;
  }

  // Check to see if the INA219 sensors should be read by comparing the delta between currentMillis and previousMillis
  if (currentMillis - previousMillis2 >= printinterval)
  {
    // Restart the non-blocking millis() timer
    previousMillis2 = currentMillis;

    display.clearDisplay();
    display.setCursor(0, 0);

    // Retrieve INA219 measurments by calling class object methods within the INA219 library, print to serial port
    Serial.print(build_unit_string(false, voltage, PWR_IN_IMON.busVoltage(), PWR_OUT_IMON.busVoltage()) + '\n');
    display.println(build_unit_string(true, voltage, PWR_IN_IMON.busVoltage(), PWR_OUT_IMON.busVoltage()) + '\n');

    // Dynamically change units displayed between A/mA depending on whether the measured current is less than or greater than a single unit
    Serial.print(build_unit_string(false, current, I_IN_AVERAGE, I_OUT_AVERAGE) + '\n');
    display.println(build_unit_string(true, current, I_IN_AVERAGE, I_OUT_AVERAGE) + '\n');

    // Dynamically change units displayed between W/mW depending on whether the measured power is less than or greater than a single unit
    Serial.println(build_unit_string(false, power, PWR_IN_IMON.busPower(), PWR_OUT_IMON.busPower()) + '\n');
    display.println(build_unit_string(true, power, PWR_IN_IMON.busPower(), PWR_OUT_IMON.busPower()));

    display.display();
  }
}

bool over_current_event()
{
  // Retrieve INA219 measurments by calling class object methods within the INA219 library
  I_IN_AVERAGE = PWR_IN_IMON.shuntCurrent();
  I_OUT_AVERAGE = PWR_OUT_IMON.shuntCurrent();

  // Check for large delta in input/output current samples over time, which influences how frequently serial data should be printed to be logged
  if (abs(I_IN_AVERAGE - I_IN_AVERAGE_PREVIOUS) > 0.01 || abs(I_OUT_AVERAGE - I_OUT_AVERAGE_PREVIOUS) > 0.01)
  {
    printinterval = 100;
  }
  else
  {
    printinterval = 10000;
  }

  // If either the input current or output current exceed the amount specified by I_MAX_EXPECTED, return true
  if (I_IN_AVERAGE > I_MAX_EXPECTED || I_OUT_AVERAGE > I_MAX_EXPECTED)
  {
    return true;
  }
  else
  {
    return false;
  }
}

bool under_voltage_event()
{
  // If input voltage falls below 16VDC, disable regulated output to prevent over-draining of the battery
  if (PWR_IN_IMON.busVoltage() < 16.0)
  {
    return true;
  }
  else
  {
    return false;
  }
}

/* This functions prints a formatted human-readable string to the serial port specified in the setup
  the string that is built is dynamically changed between units of voltage, current or power dependent upon the enumerator passed to this function
  @param electrical_unit
  @param UNIT_IN_MEASURMENT input voltage, current or power
  @param UNIT_OUT_MEASURMENT output voltage, current or power */
String build_unit_string(bool short_string, unit_type electrical_unit, float UNIT_IN_MEASUREMENT, float UNIT_OUT_MEASUREMENT)
{
  bool UNIT_IN_RANGE = UNIT_IN_MEASUREMENT >= 1.0 ? true : false;
  bool UNIT_OUT_RANGE = UNIT_OUT_MEASUREMENT >= 1.0 ? true : false;
  // Size of char array which stores floating point number is set large enough to store 4 digits e.g. XXX.X
  char UNIT_IN_STRING[6], UNIT_OUT_STRING[6];
  char UNIT_TEMP_STRING[32];
  char UNIT_STRING[32];
  UNIT_TEMP_STRING[0] = '\0';
  // Convert floating point value to char array
  dtostrf(UNIT_IN_RANGE ? UNIT_IN_MEASUREMENT : UNIT_IN_MEASUREMENT * 1000.0, UNIT_IN_RANGE ? 3 : 4, UNIT_IN_RANGE ? 2 : 1, UNIT_IN_STRING);
  dtostrf(UNIT_OUT_RANGE ? UNIT_OUT_MEASUREMENT : UNIT_OUT_MEASUREMENT * 1000.0, UNIT_OUT_RANGE ? 3 : 4, UNIT_OUT_RANGE ? 2 : 1, UNIT_OUT_STRING);
  // Char array must be populated in two parts, first by using strcpy to store the first half, then concatenate the second
  // half using strcat()
  switch (electrical_unit)
  {
    case voltage:
      if (short_string)
      {
        strcpy(UNIT_TEMP_STRING, UNIT_IN_RANGE ? "%sV" : "%smV");
        strcat(UNIT_TEMP_STRING, UNIT_OUT_RANGE ? " / %sV" : " / %smV");
      }
      else
      {
        strcpy(UNIT_TEMP_STRING, UNIT_IN_RANGE ? "V_IN/V_OUT:   %sV" : "V_IN/V_OUT:   %smV");
        strcat(UNIT_TEMP_STRING, UNIT_OUT_RANGE ? " / %sV" : " / %smV");
      }
      break;
    case current:
      if (short_string)
      {
        strcpy(UNIT_TEMP_STRING, UNIT_IN_RANGE ? "%sA" : "%smA");
        strcat(UNIT_TEMP_STRING, UNIT_OUT_RANGE ? " / %sA" : " / %smA");
      }
      else
      {
        strcpy(UNIT_TEMP_STRING, UNIT_IN_RANGE ? "I_IN/I_OUT:   %sA" : "I_IN/I_OUT:   %smA");
        strcat(UNIT_TEMP_STRING, UNIT_OUT_RANGE ? " / %sA" : " / %smA");
      }
      break;
    case power:
      if (short_string)
      {
        strcpy(UNIT_TEMP_STRING, UNIT_IN_RANGE ? "%sW" : "%smW");
        strcat(UNIT_TEMP_STRING, UNIT_OUT_RANGE ? " / %sW" : " / %smW");
      }
      else
      {
        strcpy(UNIT_TEMP_STRING, UNIT_IN_RANGE ? "P_IN/P_OUT:   %sW" : "P_IN/P_OUT:   %smW");
        strcat(UNIT_TEMP_STRING, UNIT_OUT_RANGE ? " / %sW" : " / %smW");
      }
      break;
    default:
      break;
  }
  // Insert floating point number strings into final unit string using the %s specifier
  snprintf(UNIT_STRING, sizeof(UNIT_STRING), UNIT_TEMP_STRING, UNIT_IN_STRING, UNIT_OUT_STRING);
  return UNIT_STRING;
}

// Must explicitly define dtostrf function as it is unsupported for SAMD core in the Wire.h library
char *dtostrf (double val, signed char width, unsigned char prec, char *sout)
{
  char fmt[20];
  sprintf(fmt, "%%%d.%df", width, prec);
  sprintf(sout, fmt, val);
  return sout;
}

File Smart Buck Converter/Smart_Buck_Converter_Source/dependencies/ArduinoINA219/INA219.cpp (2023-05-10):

/******************************************************************************
* TI INA219 hi-side i2c current/power monitor Library
*
* http://www.ti.com/product/ina219
*
* 6 May 2012 by John De Cristofaro
*
*
* Tested at standard i2c 100kbps signaling rate.
*
* This library does not handle triggered conversion modes. It uses the INA219
* in continuous conversion mode. All reads are from continous conversions.
*
* A note about the gain (PGA) setting:
*	The gain of the ADC pre-amplifier is programmable in the INA219, and can
*	be set between 1/8x (default) and unity. This allows a shunt voltage 
*	range of +/-320mV to +/-40mV respectively. Something to keep in mind,
*	however, is that this change in gain DOES NOT affect the resolution
*	of the ADC, which is fixed at 1uV. What it does do is increase noise
*	immunity by exploiting the integrative nature of the delta-sigma ADC.
*	For the best possible reading, you should set the gain to the range
*	of voltages that you expect to see in your particular circuit. See
*	page 15 in the datasheet for more info about the PGA.
*
* Known bugs:
*     * may return unreliable values if not connected to a bus or at
*	bus currents below 10uA.
*
* Arduino 1.0 compatible as of 6/6/2012
*
* Dependencies:
*    * Arduino Wire library
*
* MIT license
******************************************************************************/

#include "INA219.h"

#ifdef __avr__
  #include <util/delay.h>
#endif

namespace{
// config. register bit labels
const uint8_t RST =	15;
const uint8_t BRNG = 13;
const uint8_t PG_1 = 12;
const uint8_t PG_0 = 11;
const uint8_t BADC4 = 10;
const uint8_t BADC3	= 9;
const uint8_t BADC2	= 8;
const uint8_t BADC1	= 7;
const uint8_t SADC4	= 6;
const uint8_t SADC3	= 5;
const uint8_t SADC2	= 4;
const uint8_t SADC1	= 3;
const uint8_t MODE3	= 2;
const uint8_t MODE2	= 1;
const uint8_t MODE1	= 0;
};

#define CNVR_B 1  // conversion ready bit in bus voltage register V_BUS_R 
#define OVF_B  0  // math overflow bit in bus voltage register V_BUS_R 

INA219::INA219(t_i2caddr addr): i2c_address(addr) {
}

uint8_t INA219::begin() {
  uint8_t ret;
    Wire.begin();
    ret = reset();
    if (ret)
      return ret;  // Likely failed to address/find the device
    configure();
    calibrate();

    return ret;
}

void INA219::calibrate(float shunt_val, float v_shunt_max, float v_bus_max, float i_max_expected) {
    uint16_t digits;
    float min_lsb, swap;
#ifdef INA219_DEBUG
    float max_current,max_before_overflow,max_shunt_v,max_shunt_v_before_overflow,max_power,i_max_possible,max_lsb;
#endif

    r_shunt = shunt_val;

    min_lsb = i_max_expected / 32767;

    current_lsb = min_lsb;
    digits=0;

    /* From datasheet: This value was selected to be a round number near the Minimum_LSB.
     * This selection allows for good resolution with a rounded LSB.
	   * eg. 0.000610 -> 0.000700
	   */
    while( current_lsb > 0.0 ){//If zero there is something weird...
        if( (uint16_t)current_lsb / 1){
        	current_lsb = (uint16_t) current_lsb + 1;
        	current_lsb /= pow(10,digits);
        	break;
        }
        else{
        	digits++;
            current_lsb *= 10.0;
        }
    };

    swap = (0.04096)/(current_lsb*r_shunt);
    cal = (uint16_t)swap;
    power_lsb = current_lsb * 20;

#ifdef INA219_DEBUG
      i_max_possible = v_shunt_max / r_shunt;
      max_lsb = i_max_expected / 4096;
      max_current = current_lsb*32767;
      max_before_overflow =  max_current > i_max_possible?i_max_possible:max_current;

      max_shunt_v = max_before_overflow*r_shunt;
      max_shunt_v_before_overflow = max_shunt_v > v_shunt_max?v_shunt_max:max_shunt_v;

      max_power = v_bus_max * max_before_overflow;
      Serial.print("v_bus_max:     "); Serial.println(v_bus_max, 8);
      Serial.print("v_shunt_max:   "); Serial.println(v_shunt_max, 8);
      Serial.print("i_max_possible:        "); Serial.println(i_max_possible, 8);
      Serial.print("i_max_expected: "); Serial.println(i_max_expected, 8);
      Serial.print("min_lsb:       "); Serial.println(min_lsb, 12);
      Serial.print("max_lsb:       "); Serial.println(max_lsb, 12);
      Serial.print("current_lsb:   "); Serial.println(current_lsb, 12);
      Serial.print("power_lsb:     "); Serial.println(power_lsb, 8);
      Serial.println("  ");
      Serial.print("cal:           "); Serial.println(cal);
      Serial.print("r_shunt:       "); Serial.println(r_shunt, 6);
      Serial.print("max_before_overflow:       "); Serial.println(max_before_overflow,8);
      Serial.print("max_shunt_v_before_overflow:       "); Serial.println(max_shunt_v_before_overflow,8);
      Serial.print("max_power:       "); Serial.println(max_power,8);
      Serial.println("  ");
#endif
      write16(CAL_R, cal);
}

void INA219::configure(  t_range range,  t_gain gain,  t_adc  bus_adc,  t_adc shunt_adc,  t_mode mode) {
  config = 0;

  config |= (range << BRNG | gain << PG_0 | bus_adc << BADC1 | shunt_adc << SADC1 | mode);
#ifdef INA219_DEBUG
  Serial.print("Config: 0x"); Serial.println(config,HEX);
#endif
  write16(CONFIG_R, config);
}

#define INA_RESET        0xFFFF    // send to CONFIG_R to reset unit
// Returns non-zero if unable to reset.
// This is likely due to device not being functional/installed on I2C bus
// Returned error values are defined in the Wire libraries.
// Values of 2 indicates the address wasn't on the bus (NAK response)
uint8_t INA219::reset(){
  uint8_t ret = write16(CONFIG_R, INA_RESET);
  delay(5);
  return ret;
}

int16_t INA219::shuntVoltageRaw() const {
  return read16(V_SHUNT_R);
}

float INA219::shuntVoltage() const {
  float temp;
  temp = read16(V_SHUNT_R);
  return (temp / 100000);
}

uint16_t INA219::busVoltageRaw() {
  uint16_t bus_voltage_register = read16(V_BUS_R);
  _overflow = bitRead(bus_voltage_register, OVF_B);     // overflow bit
  _ready    = bitRead(bus_voltage_register, CNVR_B);    // ready bit
  return bus_voltage_register;
}


float INA219::busVoltage() {
  uint16_t temp;
  temp = busVoltageRaw();
  temp >>= 3;
  return (temp * 0.004);
}

int16_t INA219::shuntCurrentRaw() const {
  return (read16(I_SHUNT_R));
}

float INA219::shuntCurrent() const {
  return (read16(I_SHUNT_R) * current_lsb);
}

float INA219::busPower() const {
  return (read16(P_BUS_R) * power_lsb);
}

/**************************************************************************/
/*! 
    @brief  Rewrites the last config register
*/
/**************************************************************************/
void INA219::reconfig() const {
#ifdef INA219_DEBUG
  Serial.print("Reconfigure with Config: 0x"); Serial.println(config,HEX);
#endif
  write16(CONFIG_R, config);
}
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

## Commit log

2023-05-10 Initial commit
    Initial addition of project files. Added description to README.md.
    [Buck Conversion.kicad_sch, Current Monitoring.kicad_sch, Enclosure_BOTTOM.stl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]
2023-05-10 Added library dependency for INA219
    [ina219_hardware_mount.fzz]
2023-05-10 Modified .gitignore for KiCad extensions
2023-05-12 Inclusion of KiCad design dependencies
    Added custom components symbols, footprints, and 3D models used for PCB design, all of which will need to be placed in local KiCad directory for PCB design and schematic to be fully editable.
    [3362P-1-103.step, ABS25-32.768KHZ-T.step, SHF-105-01-L-D-SM.step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]
2023-05-12 Changes to README & Design
    Updated revision number of hardware design to 2.0.0, despite the changes for this revision being implemented before this project was version controlled on GitHub. Also regenerated 3D view images of revision 2 and replaced them in the README. Added detail regarding known hardware bug in README.
    [Buck Conversion.kicad_sch, Current Monitoring.kicad_sch, IO_Interface.kicad_sch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]
2023-06-07 Revision 2 update
    Regenerated gerber files to rev 2 design, made minor changes to PCB layout before exporting. Changed I2C interface connector from 4-pin right angle style to vertical style, added the new connector th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
    [BM04B-SRSS-TBT_LF__SN_.step, Buck Conversion.kicad_sch, IO_Interface.kicad_sch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]
2023-12-26 Multiple updates
    Added necessary code to support addition of either 128x64 or 128x32 OLED display from Adafruit. Fixed backwards polarity on RX/TX indicator LEDs. Updated enclosure to support addition of OLED display. Rendered shaded view of entire revision 2 assembly stack up. Generated BOM.
    [Enclosure_BOTTOM.stl, Enclosure_TOP.stl, IO_Interface.kicad_sch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]

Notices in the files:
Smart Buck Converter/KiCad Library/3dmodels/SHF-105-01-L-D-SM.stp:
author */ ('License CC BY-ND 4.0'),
